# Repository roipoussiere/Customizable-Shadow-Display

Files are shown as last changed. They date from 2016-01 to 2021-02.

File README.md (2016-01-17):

# Customizable Shadow Display
A digital display which displays whatever you want, whenever you want. No batteries, no motor, no electronics, only a 3D-printed object and its shadow.

See the [GitHub repository](https://github.com/roipoussiere/Customizable-Shadow-Display) and the [Thingiverse](http://www.thingiverse.com/thing:1253190) page.

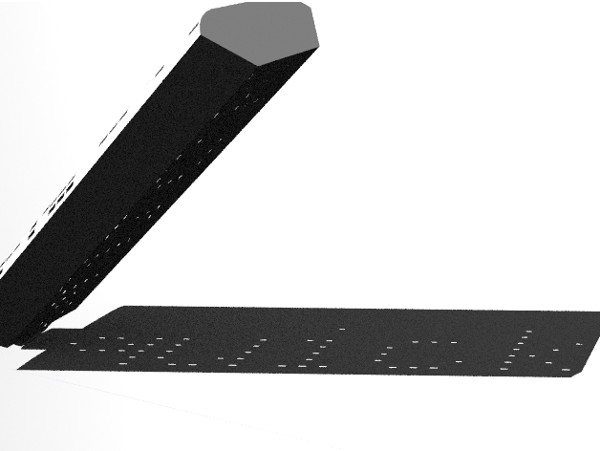
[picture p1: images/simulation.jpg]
Sundial simulation


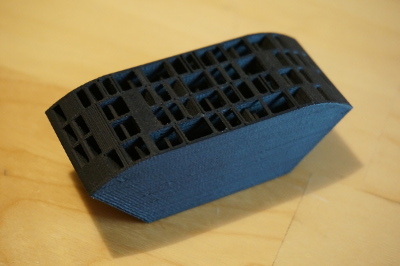
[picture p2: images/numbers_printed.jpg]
3D-printed part


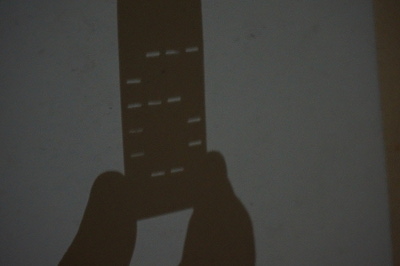
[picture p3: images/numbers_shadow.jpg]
shadow


## About the original Digital Sundial

This work is inspirated by the Mojoptix project [Mojoptix project](http://www.thingiverse.com/thing:1068443), who describes the sundial as it:

> It's a Sundial displaying the time inside its shadow, with actual digits !
> There is a tiny bit of magic inside...
>
> No batteries, no motor, no electronics... It's all just a really super-fancy shadow show. The shape of the sundial has been mathematically designed to only let through the right sunrays at the right time/angle. This allows to display the actual time with sunlit digits inside the sundial's shadow.
>
> The sundial displays time (with actual digits !!) from 10:00 until 16:00, updating every 20 minutes.
> You can precisely adjust the displayed time simply by rotating the gnomon (the magic box that displays time). So you can even adjust for Daylight Saving Time.

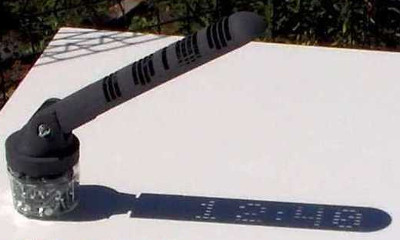
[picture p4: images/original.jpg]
Original project


Its [video podcast](http://www.mojoptix.com/2015/10/25/mojoptix-001-digital-sundial) describes this sundial in details.

## The customizable shadow display

Contrary to the Mojoptix sundial, this one allows you to display, instead of the clock numbers, whatever and whenever you want. The displayed text can be as long as you want, and can contain all usual characters. In addition, you can customize a lot a others parameters, like the digits duration or the gnomon shape.

See [the simulation](https://www.youtube.com/watch?v=YztbfwrANII&feature=youtu.be) on Youtube for the [quick_fox.stl](http://www.thingiverse.com/download:1956136) example.

The attached STL files are not required, it's just few items made with the Customizer app to show you what you can do (see *Text* option bellow).

**Note:** When rendering the sundial, you may get CGal warnings saying there are a lot of elements. If you are using the Customizer app, just ignore them. If you are using OpenSCAD on you own computer, you can increase the value of parameters *Tun off rendering at* and *cache size* in the OpenSCAD preference window.

## Available Customizer options

#### Main options

- **Text**: the text displayed on the shadow of the sundial, for each position, separated by semi-colons. For example, if you want to display "Hello", then "world" few minutes later, set this field to `Hello;world`. Try with these ones:
    - [quick_fox.stl](http://www.thingiverse.com/download:1956136): `The;quick;brown;fox;jumps;over;the;lazy;dog.`
    - [clock.stl](http://www.thingiverse.com/download:1956139): `10:00;10:20;10:40;11:00;11:20;11:40;12:00;12:20;12:40;13:00;` `13:20;13:40;14:00;14:20;14:40;15:00;15:20;15:40;16:00`
    - [numbers.stl](http://www.thingiverse.com/download:1956175): `0;1;2;3;4;5;6;7;8;9`
- **Digits duration**: the duration of each text, according to the sun rotation.
- **Hemisphere**: just select where you are;
- **basic shape** of the gnomon:
    - a half-cylinder;
    - a "boat", which is an optimized shape because each hole has the same depth.
- **holder**: to print (or not) a holder which fixes the gnomon (with a screw). The holder is Mojoptix-compatible.
- **rod**: print a pipe to hold several digits together with a rod. So you can print a 1 meter long sundial, with your 12x12 printer. ;-)
-  **font**: Font used to display the text, among 2 available fonts:
    - numbers, with 4x6 digits: `0-9`, and `:`. If your text contains other characters, an error will occurs.
    - ASCII, with 5x7 digits: `0-9`, `a-z`, `A-Z`, and ` !\"#%$&'()*+,-./:;<=>?@[\]^_``{|}~¤`, where `~` and `¤` are respectively a full black digit and a heart. Note that you can easily customize and / or add fonts by editing the scad file.
- **transition delay**: during a transition, all pixels turns to black. With no transition (0%), the piece contains less material (so it's faster to print), but digits are sometimes not clear.

#### Advanced parameters

- **remove_thin_parts** : Remove parts smaller than the specified size. This option take a very long time to process, like few hours (because it calls 2 minkowski sums). It's better to use it in your computer (not with the Customizer app). Edit the .scad with your parameters, save it and make the stl file in command line : `openscad -o sundial.stl main.scad`. It will use the OpenCSG render engine, which is faster than the CGAL render for this use case.
- **gnomon radius**
- **pixel width**
- **pixel height**
- **space between columns**
- **space between rows**
- **space between digits**
- **enlarge slots** : Enlarge the slots on the bottom on the gnomon. Big slots should improve digits readability, but can also unintentionally turn some pixels to white.
- **screw size** : the screw size used to hold the gnomon.

## Instructions

#### Step by step
- Customize your sundial with the *Makerbot Customizer* interface, then download it;
- verify the item with a rendering software (OpenSCAD, Netfabb, Blender, ...), and check the digits on each position (then eventually re-customize it). Prefer an orthogonal view than a perspective view to watch the item;
- print it with the settings bellow;
- print the other pieces [from here](www.thingiverse.com/thing:1068443);
- Put them together and enjoy;
- Please take a picture and share it on Thingiverse (by clicking on *I made
one*). I am always so happy to see what people make with my work! :-)

A bonus point to the first who prints a "sundial powered word clock", which displays the time each 15 minutes, in its literal form. :-D

#### Other required parts
- an (empty !) jam jar;
- 3x M6 screws, flat head, length = 20 mm;
- 1x M6 screw, flat head, length = 50 mm;
- 4x M6 nuts;
- 4x M6 washer, outside diameter < 14mm;

#### Print settings
Tested on a Up! Plus.

- **Raft**: Yes
- **Supports**: No
- **Resolution**: 0.15mm
- **Infill**: 10%
- **Print quality**: fast
- **Print thin parts**: No

## GitHub repository

Hi developers and hacker! Good news, the entire code is documented and easy to read and modify! It's hosted on [GitHub](https://github.com/roipoussiere/Customizable-Digital-Sundial). It's easier to work from here and there is additional useful files (like Python and Blender scripts).

1. Make a copy of *main.scad* and name it *_main.scad*;
2. Do whatever you want on this one. Personally, I prefer to work with an external IDE (like [Atom](https://atom.io/) and [this plugin](https://atom.io/packages/language-openscad)) and use OpenSCAD only to render the file;
3. Open a terminal and type `python/clean_and_merge.py` before your commit (see *Python scripts* below).

#### OpenSCAD scripts
For more readability, the .scad script is splitted in 3 files: *main*, *functions* and *fonts*.

The *functions* file uses a part of my [OpenSCAD library](http://www.thingiverse.com/thing:202724) for string and vectors operations. Take a look.

#### Python scripts
- **clean_and_merge.py**: Merge and clean the .scad files before to upload it on *Thingiverse* and *Github*:
  1. Creates `PUSHED_MAIN_FILE`, a cleaned copy of `MAIN_FILE`, by:
    - replacing the parameters by the default parameters specified in the *default_parameters* file;
    - remove contents containing `NOTE` or `value=something`.
  2. Creates `OUT_FILE`, containing all the .scad files, by:
    - replacing the `<include>` declarations by their contents (Customizer app doesn't supports multiple .scad files.).
- **compare.py**: Compare 2 .scad files representing a sundial. It slice the 3D-models in a given position, then generates a picture showing the 2 superposed slices.
- **decode_font.py**: Decode an array of numbers in hexadecimal notation and print it as a decimal array, to you use it on OpenSCAD (which doesn't support hexadecimal notation).
- **default_parameters**: a file containing default parameters, then you can modify them when you code without to be worried about publishing the file containing test parameters)

#### Blender script
This script allows you to simulate the sun shinning on the sundial. Watch [the video](https://www.youtube.com/watch?v=YztbfwrANII&feature=youtu.be) of a simulation, rendered with it.

Read [README](https://github.com/roipoussiere/Customizable-Digital-Sundial/tree/master/blender) to know how to use it.

## To come

- pixel-art display support, by editing images on a web interface;
- a video of the sundial in action (I am waiting for the sun);
- any suggested feature! ;-)

Please contact me for features or bug requests!

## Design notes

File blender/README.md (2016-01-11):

# How to render sun simulations

## 1. Download Blender
[Here](https://www.blender.org/download/). You need a recent version (>= 2.76)

## 2. Install the addon
- Download the [Sun position addon](http://wiki.blender.org/index.php/Extensions:2.6/Py/Scripts/3D_interaction/Sun_Position);
- On Blender, go to *File*, *preferences*, *Addon* tab;
- Click on *install from file* on the bottom and select the addon ;
- Then check it on the addons list, save user settings and exit the window.

## 3. Enable and configure the addon
- On the right panel, select *world view* (small rounded icon);
- On the *Sun position* tab (on the bottom), click *Enable*;
- Then click on the calendar icon to display the days numbers;

## 4. Launching the script
- Copy your .stl file into *[path_to_repository]/blender/* and name it *sundial.stl*;
- Select the *Text editor* editor type, by clicking on the small icon on the bottom-left corner;
- Click on the button *Text*, then *Open text block* then select the python script in the repository
(*[path_to_repository]/blender/sundial_simulator.py*);
- Save your Blender scene in *[path_to_repository]/blender/*;
- Click on *Run script*
- You can eventually edit *Scene_parameters.txt* and *Keyframes_parameters.csv*
to place correctly the sundial and the camera, then run the script again.

## 5. Rendering
- On the right panel, select the *Render view* (camera icon);
- On the *Output* tab, chose a destination folder and the video encoding.
Select a low resolution first, to check the sundial and camera positions;
- On the *Render* tab, click on *Animation*;
- Edit eventually *Scene_parameters.txt* and *Keyframes_parameters.csv*
to place correctly the sundial and the camera, then run the script again;
- Choose a high resolution and render the scene again.

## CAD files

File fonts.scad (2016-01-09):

/* *** CUSTOMISABLE DIGITAL SUNDIAL ***
Font file

Author: Nathanaël Jourdane
Email: nathanael@jourdane.net
Date: december 30, 2015
Licence: GPL v2 http://www.gnu.org/licenses/old-licenses/gpl-2.0.en.html#SEC1
Thingiverse: http://www.thingiverse.com/thing:1253190
GitHub: https://github.com/roipoussiere/Customizable-Digital-Sundial*/

/* You can edit the following arrays to customize your font, or create new
ones. Each font is stored in `chars_lists` and `char_fonts` on the same index.
`chars_lists` is the characters list of the fonts, while `char_fonts` is the
fonts itself.

**To modify a character:**
Edit an entry in `char_font`[font_index][char_index].

**To add a new character to a font:**
Add your character in `chars_lists`[font_index][any_char_index], then add its
font in `char_font`[font_index][same_char_index].

**To add a new font:**
Add an array of characters in `chars_lists`[any_index], then add the
corresponding array of your font in `chars_fonts`[same_font_index]

Each char in `chars_fonts` is an array of numbers representing the decimal
value of a column, where the most significant bit is the bottom of the digit.

The 5x7 font comes from: http://sunge.awardspace.com/glcd-sd/node4.html. */

/* Characters lists */

chars_lists =
// ASCII font (5x7)
[" !\"#%$&'()*+,-./0123456789:;<=>?@ABCDEFGHIJKLMNOPQRSTUVWXYZ[\\]^_`abcdefghijklmnopqrstuvwxyz{|}~¤",
// Numbers font (4x6)
"0123456789:"];

/* Characters fonts */

chars_fonts = [[
// ASCII font 5x7
[  0,   0,   0,   0,   0], // (space)
[  0,   0,  95,   0,   0], // !
[  0,   7,   0,   7,   0], // "
[ 20, 127,  20, 127,  20], // #
[ 36,  42, 127,  42,  18], // $
[ 35,  19,   8, 100,  98], // %
[ 54,  73,  85,  34,  80], // &
[  0,   5,   3,   0,   0], // '
[  0,  28,  34,  65,   0], // (
[  0,  65,  34,  28,   0], // )
[  8,  42,  28,  42,   8], // *
[  8,   8,  62,   8,   8], // +
[  0,  80,  48,   0,   0], // ,
[  8,   8,   8,   8,   8], // -
[  0,  96,  96,   0,   0], // .
[ 32,  16,   8,   4,   2], // /
[ 62,  81,  73,  69,  62], // 0
[  0,  66, 127,  64,   0], // 1
[ 66,  97,  81,  73,  70], // 2
[ 33,  65,  69,  75,  49], // 3
[ 24,  20,  18, 127,  16], // 4
[ 39,  69,  69,  69,  57], // 5
[ 60,  74,  73,  73,  48], // 6
[  1, 113,   9,   5,   3], // 7
[ 54,  73,  73,  73,  54], // 8
[  6,  73,  73,  41,  30], // 9
[  0,  54,  54,   0,   0], // :
[  0,  86,  54,   0,   0], // ;
[  0,   8,  20,  34,  65], // <
[ 20,  20,  20,  20,  20], // =
[ 65,  34,  20,   8,   0], // >
[  2,   1,  81,   9,   6], // ?
[ 50,  73, 121,  65,  62], // @
[126,  17,  17,  17, 126], // A
[127,  73,  73,  73,  54], // B
[ 62,  65,  65,  65,  34], // C
[127,  65,  65,  34,  28], // D
[127,  73,  73,  73,  65], // E
[127,   9,   9,   1,   1], // F
[ 62,  65,  65,  81,  50], // G
[127,   8,   8,   8, 127], // H
[  0,  65, 127,  65,   0], // I
[ 32,  64,  65,  63,   1], // J
[127,   8,  20,  34,  65], // K
[127,  64,  64,  64,  64], // L
[127,   2,   4,   2, 127], // M
[127,   4,   8,  16, 127], // N
[ 62,  65,  65,  65,  62], // O
[127,   9,   9,   9,   6], // P
[ 62,  65,  81,  33,  94], // Q
[127,   9,  25,  41,  70], // R
[ 70,  73,  73,  73,  49], // S
[  1,   1, 127,   1,   1], // T
[ 63,  64,  64,  64,  63], // U
[ 31,  32,  64,  32,  31], // V
[127,  32,  24,  32, 127], // W
[ 99,  20,   8,  20,  99], // X
[  3,   4, 120,   4,   3], // Y
[ 97,  81,  73,  69,  67], // Z
[  0,   0, 127,  65,  65], // [
[  2,   4,   8,  16,  32], // "\"
[ 65,  65, 127,   0,   0], // ]
[  4,   2,   1,   2,   4], // ^
[ 64,  64,  64,  64,  64], // _
[  0,   1,   2,   4,   0], // `
[ 32,  84,  84,  84, 120], // a
[127,  72,  68,  68,  56], // b
[ 56,  68,  68,  68,  32], // c
[ 56,  68,  68,  72, 127], // d
[ 56,  84,  84,  84,  24], // e
[  8, 126,   9,   1,   2], // f
[  8,  20,  84,  84,  60], // g
[127,   8,   4,   4, 120], // h
[  0,  68, 125,  64,   0], // i
[ 32,  64,  68,  61,   0], // j
[  0, 127,  16,  40,  68], // k
[  0,  65, 127,  64,   0], // l
[124,   4,  24,   4, 120], // m
[124,   8,   4,   4, 120], // n
[ 56,  68,  68,  68,  56], // o
[124,  20,  20,  20,   8], // p
[  8,  20,  20,  24, 124], // q
[124,   8,   4,   4,   8], // r
[ 72,  84,  84,  84,  32], // s
[  4,  63,  68,  64,  32], // t
[ 60,  64,  64,  32, 124], // u
[ 28,  32,  64,  32,  28], // v
[ 60,  64,  48,  64,  60], // w
[ 68,  40,  16,  40,  68], // x
[ 12,  80,  80,  80,  60], // y
[ 68, 100,  84,  76,  68], // z
[  0,   8,  54,  65,   0], // {
[  0,   0, 127,   0,   0], // |
[  0,  65,  54,   8,   0], // }
[  28, 62, 124,  62,  28], // ~ = heart
[127, 127, 127, 127, 127]  // ¤ = full dark

],[
// Numbers font 4x6
[30, 41, 37, 30], // 0
[34, 63, 32, 0 ], // 1
[50, 41, 41, 38], // 2
[18, 33, 37, 30], // 3
[15, 8,  8,  63], // 4
[39, 37, 37, 25], // 5
[30, 37, 37, 25], // 6
[33, 17, 9,  7 ], // 7
[26, 37, 37, 26], // 8
[38, 41, 41, 30], // 9
[0,  20, 0,  0 ]  // :

]];

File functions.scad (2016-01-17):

/* *** CUSTOMISABLE DIGITAL SUNDIAL ***
Functions file

Author: Nathanaël Jourdane
Email: nathanael@jourdane.net
Date: december 30, 2015
Licence: GPL v2 http://www.gnu.org/licenses/old-licenses/gpl-2.0.en.html#SEC1
Thingiverse: http://www.thingiverse.com/thing:1253190
GitHub: https://github.com/roipoussiere/Customizable-Digital-Sundial*/

// ** remove_thin_parts() { `object()`; `small_object()`; } **
// Remove thin parts of an `object`, with a *corrosive* `small_object()`.
module remove_thin_parts() {
  render(convexity = 1) {
    reverse() minkowski() {
      reverse() minkowski() { children(0); children(1); }
      children(1);
    }
  }
}

// ** reverse() { `object()`; } **
// Reverse an object. Solids becames holes, holes becames solids.
module reverse() {
  difference() {
    cube([1000, 1000, 1000], center=true);
    children();
  }
}

// ** [int] binary_size([int] `n`) **
// Returns the binary size of the number `n`, ie: 63 (0b111111) returns 6.
// - `n`: The number to converts.
function binary_size(n, s=0) =
  n == 1 ? s :
  binary_size(ceil(n/2), s+1);

// ** [vect] dec2bin([int] num, [[int] `len`]) **
// Returns a vector of booleans corresponding to the binary value of `num`.
// - `num`: The number to convert.
// - `len` (optional): The vector length. If specified, fill the MSBs with 0.
// dec2bin(42, 8); // [0, 0, 1, 0, 1, 0, 1, 0]
function dec2bin(num, length=8, v=[]) =
  len(v) == length ? v :
  num == 0 ? dec2bin(0, length, concat(0, v)) :
  dec2bin(floor(num/2), length, concat(num%2, v));

// ** [vect] split([str] `str`, [[char] `sep`]) **
// Returns a vector of substrings by cutting `str` each time where `sep` appears
// - `str`: The original string.
// - `sep`: The separator who cuts the string (" " by default).
// split("foo;bar;baz", ";"); // ["foo", "bar", "baz"]
function split(str, sep=" ", i=0, word="", v=[]) =
  i == len(str) ? concat(v, word) :
  str[i] == sep ? split(str, sep, i+1, "", concat(v, word)) :
  split(str, sep, i+1, str(word, str[i]), v);

// ** [vect] new_vector([int] `len`, [[any_type] `val`]) **
// Returns a vector with `len` elements initialised to the `val` value.
// - `len`: The length of the vector.
// - `val`: The values filled in the vector *(0 by default)*.
// new_vector(5); // [0, 0, 0, 0, 0]
function new_vector(n, val=0, v=[]) =
  n == 0 ? v :
  new_vector(n-1, val, concat(v, val));

/*** Functions to get the number of rows and columns ***/

// ** [int] get_nb_rows() **
// Returns the number of pixel rows of the display: it's the heighter letter
// used in the text (based on the chars_fonts[font]).
function get_nb_rows(i=0, nbrow=0) =
  i==len(chars_fonts[font]) ? binary_size(nbrow) :
  get_nb_rows(i+1, max(chars_fonts[font][i][1]) > nbrow ?
  max(chars_fonts[font][i][1]) : nbrow);

// ** [int] get_nb_cols() **
// Returns the number of pixel columns of the display: it's the maximum text
// width ( = summ of each digit width) for all positions.
function get_nb_digits(i=-1, nb_digits=0, v=[]) =
  i == -1 ? get_nb_digits(0, 0, split(text, ";")) :
  i == len(v)-1 ? nb_digits :
  get_nb_digits(i+1, len(v[i]) > nb_digits ? len(v[i]) : nb_digits, v);

/*** Functions to make the pixel array from the customized text ***/

// [vect] char2digit([str] `char`)
// Returns an array representing a digit who displays the specified `char`.
// - `char`: the character to convert.
// char2digit("1"); // [[0, 1, 1, 1, 1, 0], [1, 0, 0, 1, 0, 1],
// [1, 0, 1, 0, 0, 1], [0, 1, 1, 1, 1, 0]]
function char2digit(char, i=-1, digit=[]) =
  i == -1 ?
    (len(char) != 1 || search(chars_fonts[font], char) == undef) ? undef :
    char2digit(chars_fonts[font][search(char, chars_lists[font])[0]], 0):
  i == len(char) ? digit :
    char2digit(char, i+1, concat(digit, [dec2bin(char[i], nb_rows)]));

// [vect] word2digits([str] `word`)
// Returns an array of digits columns who displays the specified string `str`.
// - `word`: The string to converts.
// word2digits("123"); // vector digits made with char2digit()
function word2digits(word, v=[], i=0) =
  i == len(word) ? v :
  i == len(word)-1 ? word2digits(word, concat(v, char2digit(word[i])), i+1) :
  word2digits(word, concat(v, char2digit(word[i])), i+1);

// [vect] text2digits([str] `txt`)
// Returns an array of digits columns who displays the user specified `txt`
// - `txt`: a string with words for all positions, separated by a semicolon.
// text2digits("12;34"); // vector of vectors of digits made with word2digits()
function text2digits(txt, i=-1, v=[]) =
  i == -1 ? text2digits(split(txt, ";"), 0) :
  i == len(txt) ? v :
  text2digits(txt, i+1, concat(v, [word2digits(txt[i])]));

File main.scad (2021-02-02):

/* *** CUSTOMISABLE SHADOW DISPLAY ***

Author: Nathanaël Jourdane
Email: nathanael@jourdane.net
Date: december 30, 2015
Licence: GPL v2 http://www.gnu.org/licenses/old-licenses/gpl-2.0.en.html#SEC1
Thingiverse: http://www.thingiverse.com/thing:1253190
GitHub: https://github.com/roipoussiere/Customizable-Digital-Sundial*/

/*** Customizer parameters ***/


/* [Main] */

// preview[view:south west]

// For each positions, separated by ';'.
text = "The;quick;brown;fox;jumps;over;the;lazy;dog.";

// In minutes
digit_duration = 20; // [5:120]

// Used to display the digits.
font = 0; // [0:ASCII (5x7),1:Numbers (4x6)]

// Duration between each digits (in %).
transition = 45; // [0:100]

// Where are you ?
hemisphere = 0;  // [0:Northen hemisphere, 1:Southen hemisphere]

gnomon_shape = 0; // [0:Boat, 1:Half-cylinder]

// To hold the gnomon.
holder = 1; // [1:Yes,0:No]

// To hold pieces together with a rod.
rod = 0; // [0:No, 1:2mm, 2:3mm, 3:4mm, 4:5mm]

/* [Advanced] */

// Usually your slicer software do this. Take a very long time to process.
remove_thin_parts = 0; // [0:Nope, 1:0.05mm, 2:0.10mm, 3:0.15mm, 4:0.20mm, 5:0.30mm]
gnomon_radius = 25; // [5:50]
pixel_width = 6; // [2:20]
pixel_height = 1; // [0.5:5]
space_between_columns = 1; // [0.5:5]
space_between_rows = 7.5; // [0.5:10]
space_between_digits = 3; // [1:10]
// ...on the bottom of the gnomon.
enlarge_slots = 2; // [0: No, 1: XS (x1.25), 2:S (x1.5), 3: M(x2), 4: L (x2.5), 5: XL (x3)]
screw_size = 3; // [0:M3, 1:M4, 2:M5, 3:M6, 4:M8, 5:M10]

 
 // Optimization.
 optimization = 1; // [1:Yes,0:No]
 

/*** Fonts ***/
include <fonts.scad>

/*** Generic functions for strings, vectors and numbers operations ***/
include <functions.scad>

/*** Useful shortcuts :-) ***/

module t(x=0,y=0,z=0) { translate([x,y,z]) children(); }
module r(x=0,y=0,z=0) { rotate([x,y,z]) children(); }

gnom_rad = gnomon_radius;
px_w     = pixel_width;
px_h     = pixel_height / 2; // because the holes rotation increase it
sp_col   = space_between_columns;
sp_row   = space_between_rows;
sp_char  = space_between_digits;

/*** Hidden variables on the Customizer-GUI ***/

holder_dist = 2; // distance between the nut hole and the digits
washer_dist = 2; // distance between the washer and the top of the gnomon
diam_dist   = 2; // difference between the washer and the holder diameter

/*** Computed variables ***/

/* Numbers */
nb_rows = get_nb_rows(); // number of rows
nb_digits = get_nb_digits(); // number of digits (maximum of each positions)
nb_col = nb_digits * len(chars_fonts[font][0]); // number of columns
nb_pos = len(split(text, ";")); // number of solar positions

digit_angle = digit_duration * 360/24/60; // angle between each position
total_angle = digit_angle * nb_pos ; // angle between the first to the last pos

/* Pieces dimentions */
gnom_len = nb_col*(px_w+sp_col) + (nb_digits-1)*sp_char + sp_col;
holes_diam = gnomon_shape == 1 ? // holes arcs diameter
  (gnom_rad+5)*2 / cos(total_angle/2) + 1 :  // half-cylinder shape
  gnom_rad*2 / sin((180-total_angle)/2) + 1; // boat shape
grid_width = sp_row * (nb_rows-1);
// pixel width on the surface of the cylinder
surface_px_h = (100-transition)/100*holes_diam*3.1415 * digit_angle/(360*px_h);
slots_factor = [1, 1.25, 1.5, 2, 2.5, 3][enlarge_slots];
rod_diam = [0, 2, 3, 4, 5][rod] + 0.3;
remove_box_size = [0, 0.05, 0.10, 0.15, 0.20, 0.30][remove_thin_parts];
/* Positions */
gnomon_center_y = (grid_width+4)/2 + px_h; // position of gnomon center
pixel_pos_y = gnom_rad - grid_width/2; // y pos of the first pixel
pixels = text2digits(text); // array of pixels representing the text

/* Holder */

// screw size:  M3   M4   M5   M6   M8   M10
screw_diam   = [3  , 4  , 5  , 6  , 8  , 10 ][screw_size] + 0.5;
nut_thick    = [2.4, 3.2, 4.7, 5.2, 6.8, 8.4][screw_size] + 1;
nut_width    = [5.5, 7  , 8  , 10 , 13 , 17 ][screw_size] + 0.5;
washer_diam  = [12 , 14 , 16 , 18 , 22 , 27 ][screw_size] + 1;
washer_thick = [0.8, 0.8, 1  , 1.2, 1.5, 2  ][screw_size] + 1;
holder_len = washer_dist + washer_thick + nut_thick + holder_dist;

/*** Modules to build the gnomon ***/

// Build positive holes for each pixel. Need to be substracted from the gnomon.
module holes() {
  // position of the first pixel
   t(x = px_w/2 - sp_char + sp_col, y = pixel_pos_y) {
 
 // for each pixel, build a positive hole by extruding a square.
   for(i=[0:nb_col-1], j=[0:nb_rows-1], k=[0:nb_pos])
     if(pixels[k][hemisphere ? nb_col-1-i : i][j] == 1) {
       t(x = i * (px_w+sp_col) + sp_char*(ceil((i+1)/len(chars_fonts[font][0]))),
             y = (hemisphere ? nb_rows-1-j : j) * sp_row) {
         t(x=-sp_char) r(y=90)
           cylinder(d=px_h*slots_factor, h=px_w, $fn=10);
         r(x = (nb_pos-k-0.5) * digit_angle - (90-(180-total_angle)/2) ) {
 			t(z = holes_diam/4 - 0.5)
 			linear_extrude(height=holes_diam/2, scale=[1,surface_px_h], center=true)
 				square([px_w, px_h], center=true);
 //Optimization by Margu
 			if ((optimization==1) && (k<nb_pos) && (pixels[k+1][hemisphere ? nb_col-1-i : i][j] == 1)) {
 				r(x = (-0.5) * digit_angle )
 				t(z = holes_diam/4 - 0.5)
 				linear_extrude(height=holes_diam/2, scale=[1,surface_px_h], center=true)
 				  square([px_w, px_h], center=true);
 			}
 //End of Optimization by Margu
 		}
 	  }	
     }
   }
 }

module cleaned_holes() {
  if(remove_thin_parts == 0) {
    holes();
  } else {
    remove_thin_parts() {
      holes();
      cube([remove_box_size, remove_box_size, remove_box_size]);
    }
  }
}
// Build the holder
module holder() {
  difference() {
    t(x=-holder_len, y=gnomon_center_y, z=washer_diam/2) r(y=90)
      cylinder(d=washer_diam+2*diam_dist, h=holder_len, $fn=30);
    union() {
      t(x=-holder_len, z=-10)
        cube([holder_len, grid_width+4, 10]);

      t(x=-holder_dist, y=gnomon_center_y, z=-0.1) {
        t(x=-nut_thick, y=-nut_width/2)
          cube([nut_thick, nut_width, washer_diam/2]);
        t(x=-nut_thick, z=washer_diam/2) r(y=90)
          cylinder(d=(nut_width)*1.14, h=nut_thick, $fn=6);

        t(x=-nut_thick-washer_thick, y=-washer_diam/2)
          cube([washer_thick, washer_diam, washer_diam/2]);
        t(x=-nut_thick-washer_thick, z=washer_diam/2) r(y=90)
          cylinder(d=washer_diam, h=washer_thick, $fn=50);

        t(x=-nut_thick-washer_thick-washer_dist-1, z=washer_diam/2) r(y=90)
          cylinder(d=screw_diam, h=washer_dist+1, $fn=30);
      }
    }
  }

}

// Build the half of the gnomon.
module half_gnomon() {
t(y=-gnom_rad)
  intersection() {
    t(y=pixel_pos_y) r(y=90)
      cylinder(r=gnom_rad, h=gnom_len, $fn=100);
    union() {
      t(y=pixel_pos_y-2) r(x=(90-(180-total_angle)/2))
        cube([gnom_len, gnom_rad*2, gnom_rad*2]);
      if (rod !=0 ) t(y=-rod_diam*0.63) difference() {
        union() {
          cube([gnom_len, rod_diam+3, rod_diam+3]);
          t(z=(rod_diam+3)/2) r(y=90)
            cylinder(d=rod_diam+3, h=gnom_len, $fn=20);
        }
        t(z=(rod_diam+3)/2) r(y=90)
          cylinder(d=rod_diam, h=gnom_len, $fn=20);
      }
    }
  }
}

// Build the basic shape of the gnomon, without the holes.
module gnomon() {
  if(holder)
    holder();
  if(gnomon_shape == 0) { // boat shape
    t(y=gnom_rad) {
      half_gnomon();
      mirror([0,1,0]) half_gnomon();
    }
  t(y=pixel_pos_y-2)
    cube([gnom_len, grid_width+4, gnom_rad]);
  } else { // half-cylinder shape
    t(y=(-5))
    intersection() {
      cube([gnom_len, (gnom_rad+5)*2, gnom_rad+5]);
      r(90, 0, 90) t(gnom_rad+5, 0, 0)
        cylinder(r=gnom_rad+5, h=gnom_len, $fn=100);
    }
  }
}

difference() { gnomon(); cleaned_holes(); }

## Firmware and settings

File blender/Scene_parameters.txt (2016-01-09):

[Parameters]
STL_filename = sundial.stl
STL_scale_x = 0.01
STL_scale_y = 0.01
STL_scale_z = 0.01
STL_position_x = 0
STL_position_y = 0
STL_position_z = 0.1
STL_rotation_x = 0
STL_rotation_y = -45
STL_rotation_z = 90

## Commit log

2016-01-09 First upload
    [Keyframes_parameters.csv, Scene_parameters.txt, fonts.scad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]
2016-01-11 add 'remove_thin_parts' option
    [functions.scad, main.scad]
2016-01-17 clean the file.
    [functions.scad, main.scad]
2016-01-17 rename the projet to 'shadow display'. Now it's not really a sundial, in fact.
    [main.scad]
2016-01-21 Update main.scad
    J'ai modifié directement le fichier en modifiant le module holes() et en rajoutant une variable.
    Je l'avais déjà fait hier soir mais la modification a disparu (peut-être quand j'ai supprimé le pull request pour ma première modification en annule/remplace de ton fichier main.scad)
    [main.scad]
2021-01-13 Fixed breakage introduced by pull request #2
    [main.scad]
